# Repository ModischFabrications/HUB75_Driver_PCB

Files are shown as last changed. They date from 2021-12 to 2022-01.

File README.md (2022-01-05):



# HUB75_Driver_PCB

This is the PCB for my custom HUB75 RGB Panel Display.

I bought [this 64x32 panel](https://www.aliexpress.com/item/32810362851.html) and [this ESP32 (ESP32-CH9102X)](https://www.aliexpress.com/item/32959541446.html) closely researching specifications, costing ~30€ in sum. Others will probably work too, no guarantees either way. 

Open like regular in KiCad. Look into the docs zip under [Actions/KiCad Exports](https://github.com/ModischFabrications/HUB75_Driver_PCB/actions/workflows/exports.yml) to see renderings. 

This schematic can be soldered manually onto a perfboard, but feel free to order a PCB instead. 

Use a **5V** power supply with 10W or more! 
Never connect USB Power and Matrix power together, make sure to remove the jumper when using the USB connector. 
Powering the Matrix via USB, without the terminals, is possible, but definitely not recommended, the devboard can't handle it. 

Max current is ~2A, typical ~0.7A, idle (without output) is still ~0.06A, split between devboard and RGB controllers. 
Being wireless it nice, but usually, especially in this case, not worth the effort for protoypes. 
While technically possible, the power draw will reduce battery runtime to less than a day.  

Feel free to add external solutions though, should be easy to cram a 18650 USP board into the case. 

## Decisions

Size and exact positioning is determined by the backing struts of my panel. 

Using a 30 Pin Devboard keeps everything compact, but means that IO options are limited. Many pins of the ESP32 have limited usability or are otherwise reserved, check [pinouts](https://i0.wp.com/randomnerdtutorials.com/wp-content/uploads/2018/08/ESP32-DOIT-DEVKIT-V1-Board-Pinout-30-GPIOs-Copy.png) for reference. This board contains 2 (/3) Touch Inputs for future expansion, a full I2C/SPI/... wasn't included due to size constraints. 

### Electrical

Short-circuit-resistance of the power leads is archieved using a polyfuse. Resistance of the inputs is build-in, as they are high impedance, but the outputs are at risk. 

Reverse polarity protection is given through D1, which will trigger the fuse. Sure, it's not perfect, but it's simple. 

Introducing series resistances into every single connection could have made it safer, but I can't be arsed at the moment. Active-Low or High doesn't really matter either, a cross between adjacent leads would result in one overloading regardless. Feel free to insert ~300 ohm everywhere if you want to be safe. 

## References
To be honest, they are virtually identical solutions with just minor differences. Choose according to your needs. 

- https://github.com/rorosaurus/esp32-hub75-driver
- https://github.com/witnessmenow/ESP32-i2s-Matrix-Shield

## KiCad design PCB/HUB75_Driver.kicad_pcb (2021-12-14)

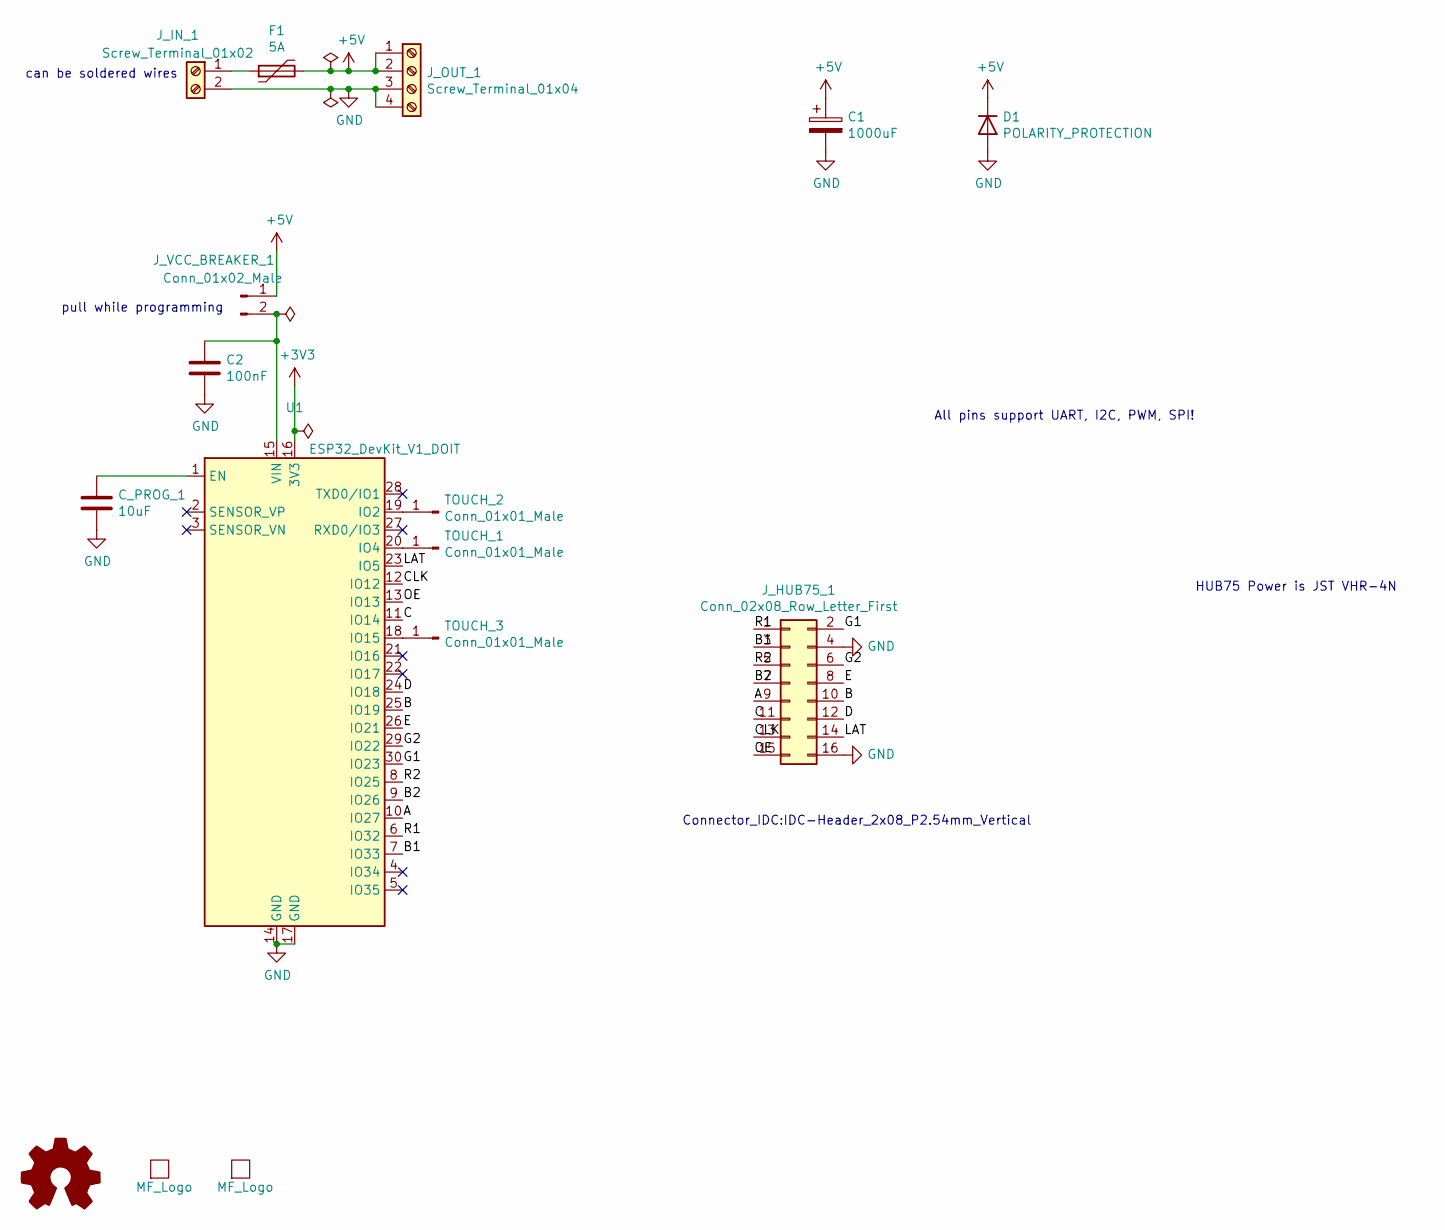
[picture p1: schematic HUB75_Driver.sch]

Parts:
C1: 1000uF; CP_10x20mm_hor
C2: 100nF; C_0603_1608Metric
C_PROG_1: 10uF; C_0603_1608Metric
D1: POLARITY_PROTECTION; D_DO-35_SOD27_P7.62mm_Horizontal
F1: 5A; Fuse_0805_2012Metric_Pad1.15x1.40mm_HandSolder
J_HUB75_1: Conn_02x08_Row_Letter_First; PinSocket_2x08_P2.54mm_Vertical
J_IN_1: Screw_Terminal_01x02; TerminalBlock_bornier-2_P5.08mm
J_OUT_1: Screw_Terminal_01x04; TerminalBlock_bornier-4_P5.08mm
J_VCC_BREAKER_1: Conn_01x02_Male; PinHeader_1x02_P2.54mm_Horizontal
L1, L2: MF_Logo; mf_logo_10mm
LOGO1: Logo_Open_Hardware_Small; OSHW-Logo2_7.3x6mm_SilkScreen
TOUCH_1, TOUCH_2, TOUCH_3: Conn_01x01_Male; PinHeader_1x01_P2.54mm_Horizontal
U1: ESP32_DevKit_V1_DOIT; esp32_devkit_v1_doit

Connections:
+5V: C1.1, D1.1 (K), F1.2, J_OUT_1.1, J_OUT_1.2, J_VCC_BREAKER_1.1
/A: J_HUB75_1.9, U1.10 (IO27)
/B: J_HUB75_1.10, U1.25 (IO19)
/B1: J_HUB75_1.3, U1.7 (IO33)
/B2: J_HUB75_1.7, U1.9 (IO26)
/C: J_HUB75_1.11, U1.11 (IO14)
/CLK: J_HUB75_1.13, U1.12 (IO12)
/D: J_HUB75_1.12, U1.24 (IO18)
/E: J_HUB75_1.8, U1.26 (IO21)
/G1: J_HUB75_1.2, U1.30 (IO23)
/G2: J_HUB75_1.6, U1.29 (IO22)
/LAT: J_HUB75_1.14, U1.23 (IO5)
/OE: J_HUB75_1.15, U1.13 (IO13)
/R1: J_HUB75_1.1, U1.6 (IO32)
/R2: J_HUB75_1.5, U1.8 (IO25)
GND: C1.2, C2.2, C_PROG_1.2, D1.2 (A), J_HUB75_1.4, J_HUB75_1.16, J_IN_1.2, J_OUT_1.3, J_OUT_1.4, U1.14 (GND), U1.17 (GND)
unnamed: C2.1, J_VCC_BREAKER_1.2, U1.15 (VIN)
unnamed: C_PROG_1.1, U1.1 (EN)
unnamed: F1.1, J_IN_1.1
unnamed: TOUCH_1.1, U1.20 (IO4)
unnamed: TOUCH_2.1, U1.19 (IO2)
unnamed: TOUCH_3.1, U1.18 (IO15)

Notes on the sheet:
can be soldered wires
pull while programming
HUB75 Power is JST VHR-4N
All pins support UART, I2C, PWM, SPI!
Connector_IDC:IDC-Header_2x08_P2.54mm_Vertical

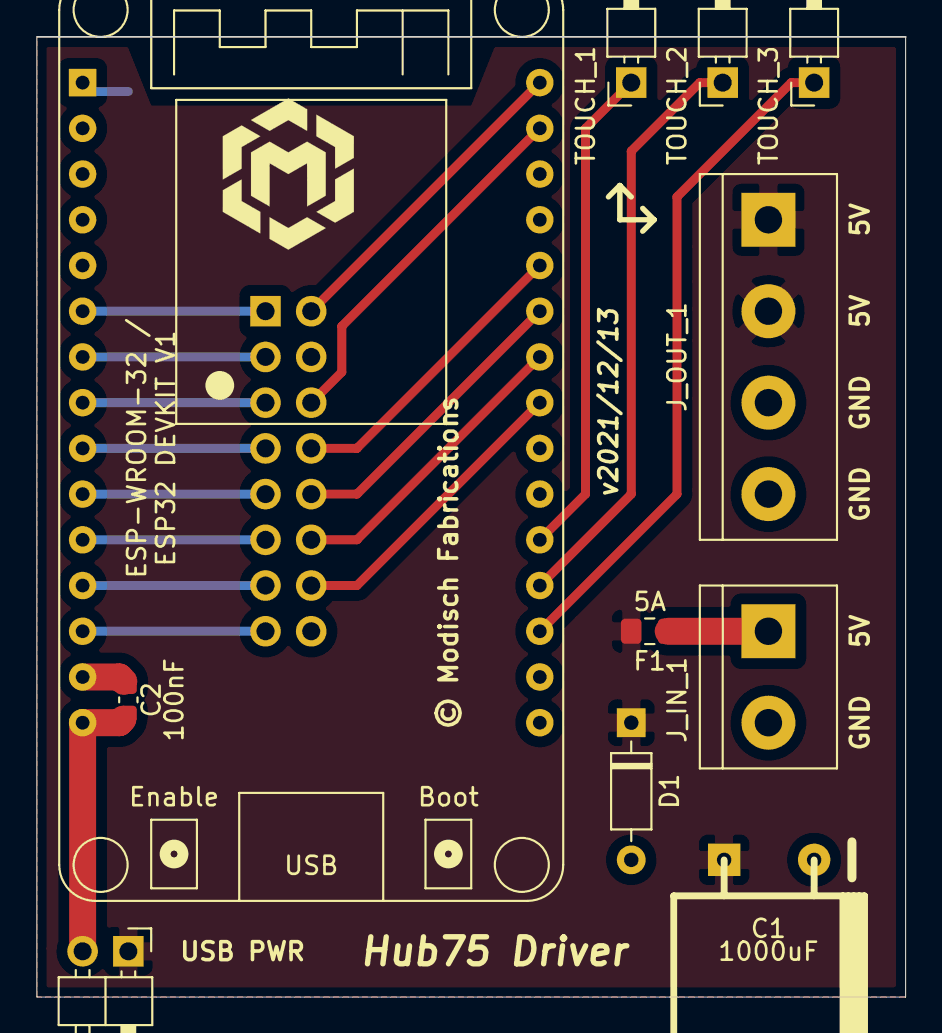
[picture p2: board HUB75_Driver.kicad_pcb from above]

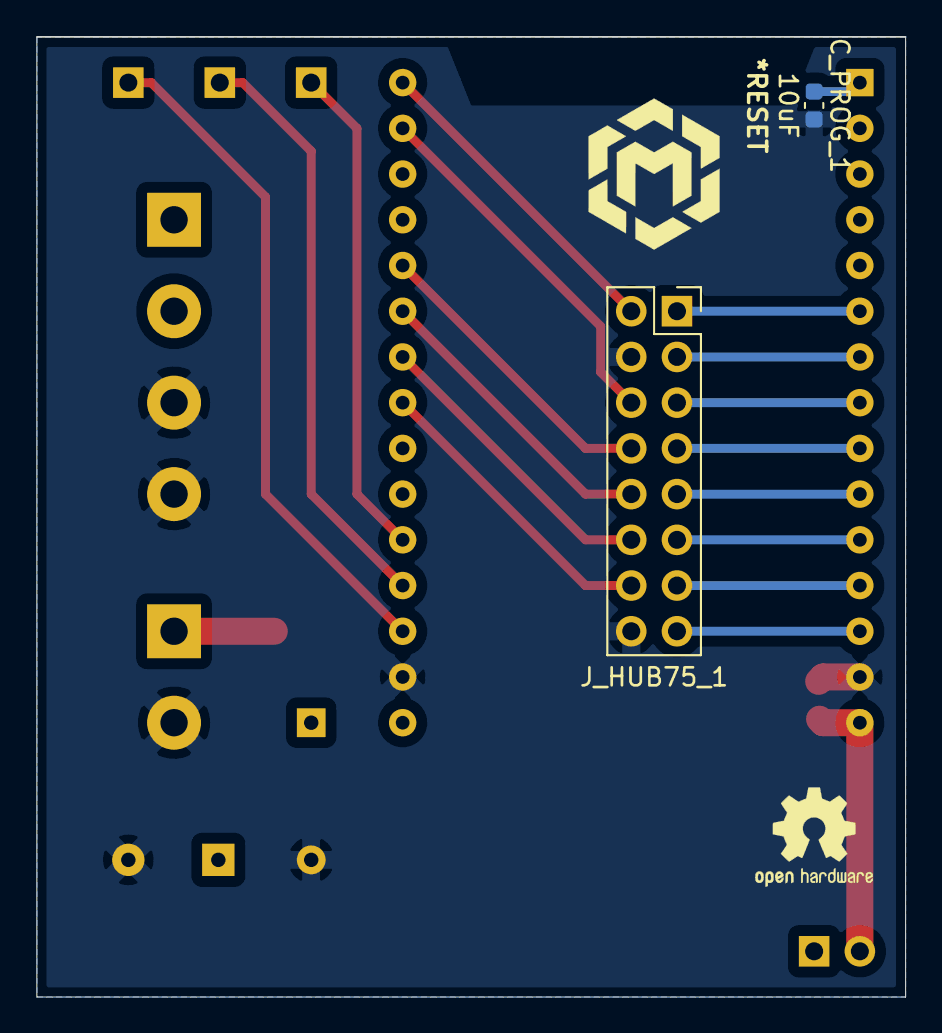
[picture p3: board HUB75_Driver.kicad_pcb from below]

Board: 2 copper layers, 48.3 x 53.3 mm, 16 parts (4 on the bottom side), 22 nets.

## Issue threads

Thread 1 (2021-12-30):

Improvements for v2

ModischFabrications, 2021-12-30:
1. increase pad size for polyfuse, currently 1:1
2. reduce hole size for screw terminals, probably 80%

ModischFabrications, 2021-12-30:
Don't use GPIO2 / Touch 2, that one seems to be reserved on some boards...

ModischFabrications, 2021-12-30:
Touch2/Top seems to be connected to the onboard LED, can't use it for touch. Look for some other pin!
https://github.com/espressif/arduino-esp32/files/1215494/SchematicsforESP32.pdf

ModischFabrications, 2021-12-30:
Align PCB differently, Pins sadly collide with frame.

ModischFabrications, 2021-12-30:
https://i0.wp.com/randomnerdtutorials.com/wp-content/uploads/2018/08/ESP32-DOIT-DEVKIT-V1-Board-Pinout-30-GPIOs-Copy.png

Seems like left side top 5 are input only and every other is in use already. Left side of HUB75 is therefore fixed.

Might be possible to shift right side around a bit, e.g. by routing GPIO32 from side side and using that ones touch.

ModischFabrications, 2022-01-05:
Fuse ~3A,?

ModischFabrications, 2023-02-12:
Copy over settings from Easylight, compare fuse against surrounding projects

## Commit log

2021-12-13 fix missing wires, use blue PCB
    [HUB75_Driver.kicad_pcb]
2021-12-14 add reset capacitor
    [HUB75_Driver.kicad_pcb, HUB75_Driver.sch]

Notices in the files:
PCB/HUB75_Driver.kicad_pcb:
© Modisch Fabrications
